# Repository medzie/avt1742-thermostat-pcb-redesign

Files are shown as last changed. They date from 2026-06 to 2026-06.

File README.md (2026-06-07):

# AVT1742 Thermostat - PCB Redesign & Optimization

A hardware cloning and optimization project based on the commercial AVT1742 extended thermostat kit. The core engineering challenge was adapting the original dual-layer design into a strict **single-layer PCB** constraint while systematically improving signal integrity and power routing.

## Key Features & Engineering Challenges

* **Single-Layer Constraint:** Redesigned the entire circuit from scratch to fit a single copper layer (Bottom) to meet strict manufacturing limitations.
* **Solid Ground Pour:** Replaced the original fragmented ground tracks with a continuous copper ground pour. This significantly lowers ground impedance and improves the overall noise immunity of the comparator circuits.
* **Component Placement Optimization:** Relocated decoupling capacitors (C4, C5) significantly closer to the IC power pins (`VCC`/`GND` of LM393 and CD4011) to minimize parasitic inductance and optimize decoupling efficiency.
* **Proven Hardware:** The board was successfully manufactured, soldered, and fully tested. It is 100% operational.

## Technical Overview

* **Core ICs:** LM393 (Low-Power Dual Voltage Comparator), CD4011 (Quad 2-Input NAND Gate)
* **Sensor:** NTC 22kΩ Thermistor
* **Outputs:** 3x Open-Collector outputs with LED status indicators (Too Low, Temp OK, Too High)
* **CAD Software:** Autodesk Eagle

## Repository Structure

* `hardware/` - Eagle CAD schematic (`.sch`) and PCB layout (`.brd`) files.
* `docs/` - Technical documentation, university project report, and original kit datasheets.
* `photos/` - Visual assets, including schematic captures, layout configurations, and hardware testing.

## Gallery & Visualization

### Hardware & PCB Design
Here is the redesigned single-layer PCB layout with the optimized component placement and solid ground pour:

* **Schematic Preview:**
Schematic Preview

* **PCB Layout & Tracks (Bottom Layer):**
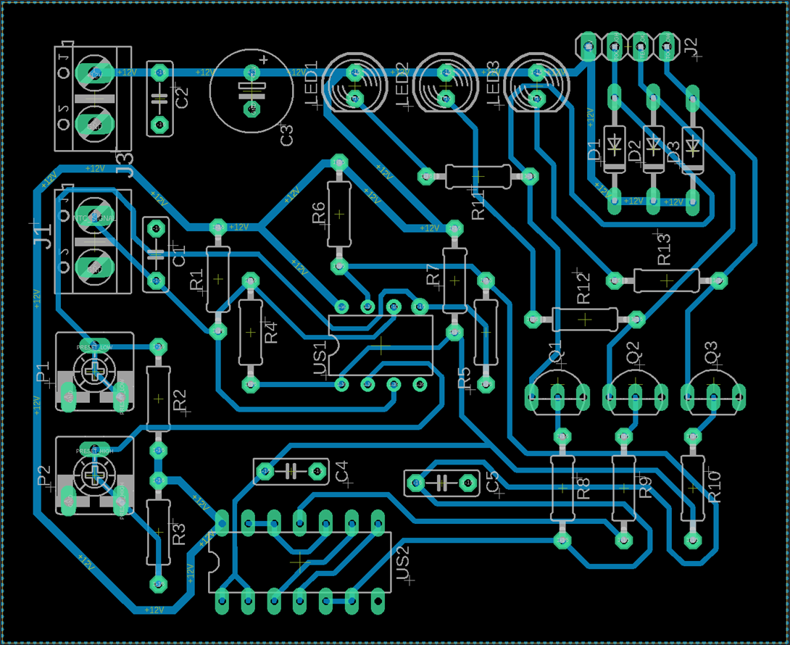
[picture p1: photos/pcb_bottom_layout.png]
PCB Layout


### Assembled & Working Device
Photos of the manufactured, soldered, and fully operational thermostat circuit:

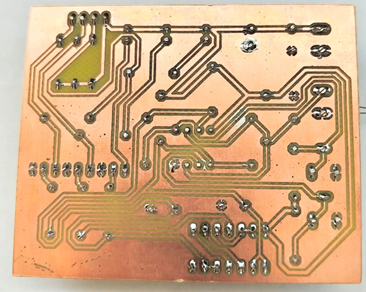
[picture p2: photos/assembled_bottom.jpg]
Assembled Board

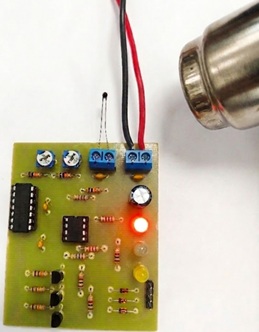
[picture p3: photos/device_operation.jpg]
Device in Action


---
*Project developed as part of engineering coursework.*

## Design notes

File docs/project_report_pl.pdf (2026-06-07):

WYDZIAŁ ELEKTRYCZNY
Studia niestacjonarne

Laboratorium Projektowanie i konstrukcja urządzeń

Data wykonania ćwiczenia: 24.05.2026 | Nazwisko Imię:
| Magdalena Woźniak
| Prowadzący:
| Łukasz Łatfis Semestr:
Data oddania sprawozdania: 06.06.2026 | 4

Temat: Wykonanie, montaż i uruchomienie
własnego układu elektronicznego | Rok: 2

### 1. Cel ćwiczenia

Praktyczne wykonanie płytki drukowanej (PCB) w warunkach pracowni, montaż elementów przewlekanych (THT) oraz test poprawnego działania układu.

### 2. Opis działania układu (AVT1742) Układ pełni funkcję dwustanowego termostatu

okienkowego, którego zadaniem jest monitorowanie, czy temperatura znajduje się w określonym przedziale. Sercem układu jest podwójny komparator analogowy LM393, który porównuje napięcie z czujnika temperatury (termistora NTC) z napięciami odniesienia ustawianymi za pomocą dwóch potencjometrów montażowych (odpowiedzialnych za próg dolny i górny). Sygnały z komparatora trafiają na bramki logiczne układu CD4011, które sterują zapalaniem odpowiedniej diody LED: pomarańczowej (zbyt niska temperatura), zielonej (temperatura w normie) lub czerwonej (przekroczenie progu górnego).

### 2. Wykaz aparatury i materiałów

- Laminat pokryty emulsją światłoczułą
- Przezroczysta folia z nadrukowaną mozaiką ścieżek
- Naświetlarka UV
- Wywoływacz, wytrawiarka z nadsiarczanem sodu
- Wiertarka stołowa (wiertła 0.8 mm, 1.0 mm),
- Stacja lutownicza, cyna (Sn63Pb37),
- Lutownica, zasilacz laboratoryjny 12V, opalarka, multimetr.

### 3. Przebieg prac

1. Trawienie: Płytkę wytrawiono w roztworze Na2S2O8 w temperaturze ok. 45°C przy włączonym napowietrzaniu (czas: ok. 15 minut) a następnie opłukano wodą.
2. Wiercenie: Na wiertarce stołowej wykonano otwory pod elementy:
- 0.8 mm: rezystory, diody, podstawki pod układy scalone, tranzystory
- 1.0 mm: potencjometry, złącza, piny
3. Montaż: Polutowano elementy metodą THT, zaczynając od najniższych (rezystory), kończąc na najwyższych (złącza i kondensator). Układy scalone (LM393 i CD4011) umieszczono w podstawkach, aby ich nie przegrzać.

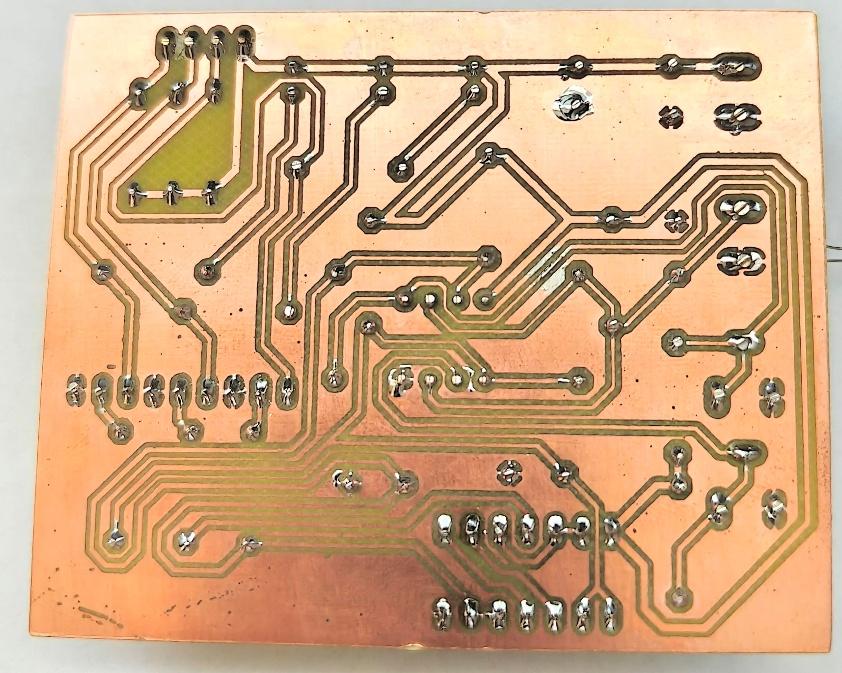
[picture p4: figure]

### 4. Test działania i uruchomienie

Przed podłączeniem zasilania sprawdzono multimetrem brak zwarć na liniach zasilających. Układ podłączono pod zasilacz laboratoryjny 12 V.
- Temperatura ciała człowieka: Układ działa prawidłowo – świeci się zielona dioda (temperatura w zadanym oknie).

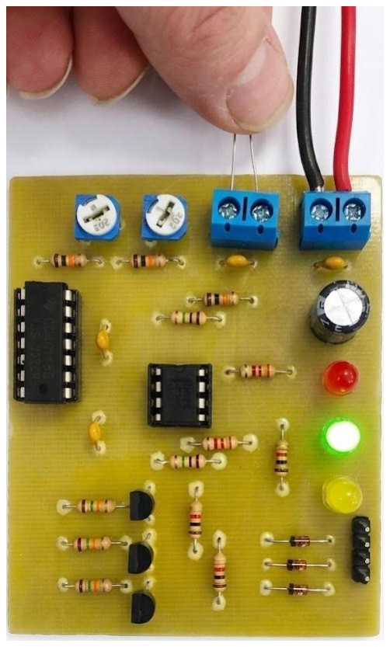
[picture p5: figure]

- Temperatura poniżej ustawionej: świeci się pomarańczowa dioda (temperatura poniżej zadanego okna).

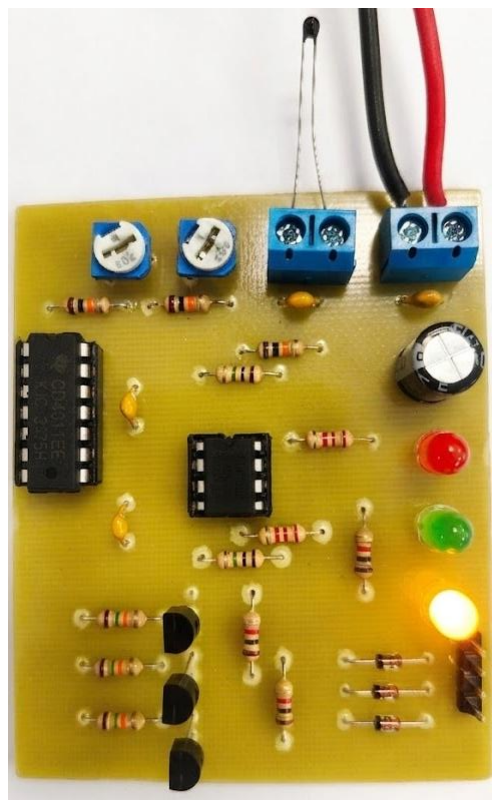
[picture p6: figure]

- Test opalarką: Po skierowaniu strumienia ciepłego powietrza z opalarki na termistor NTC, jego rezystancja spadła. Układ natychmiast zareagował: zgasła dioda zielona, a zapaliła się czerwona (przekroczenie progu górnego). Po ostygnięciu czujnik samoczynnie powrócił do stanu pomarańczowego.

### 5. Wnioski

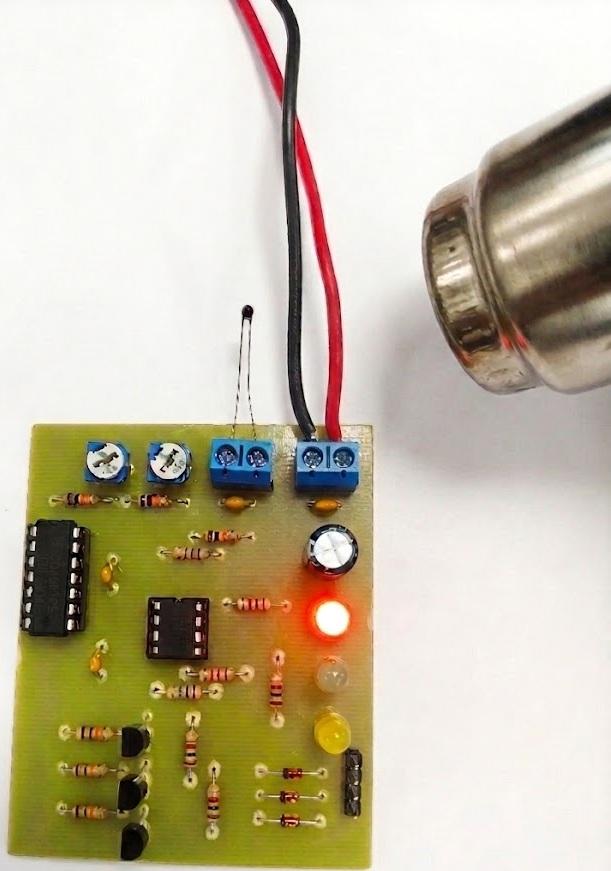
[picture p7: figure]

- Proces wytrawiania i wiercenia przebiegł pomyślnie - ścieżki są ciągłe i niepodtrawione.
- Lutowanie THT wykonano prawidłowo, brak zimnych lutów.
- Układ AVT 1742 przeszedł testy dynamiczne (reakcja na ciepło z opalarki) i wykazuje pełną sprawność funkcjonalną.

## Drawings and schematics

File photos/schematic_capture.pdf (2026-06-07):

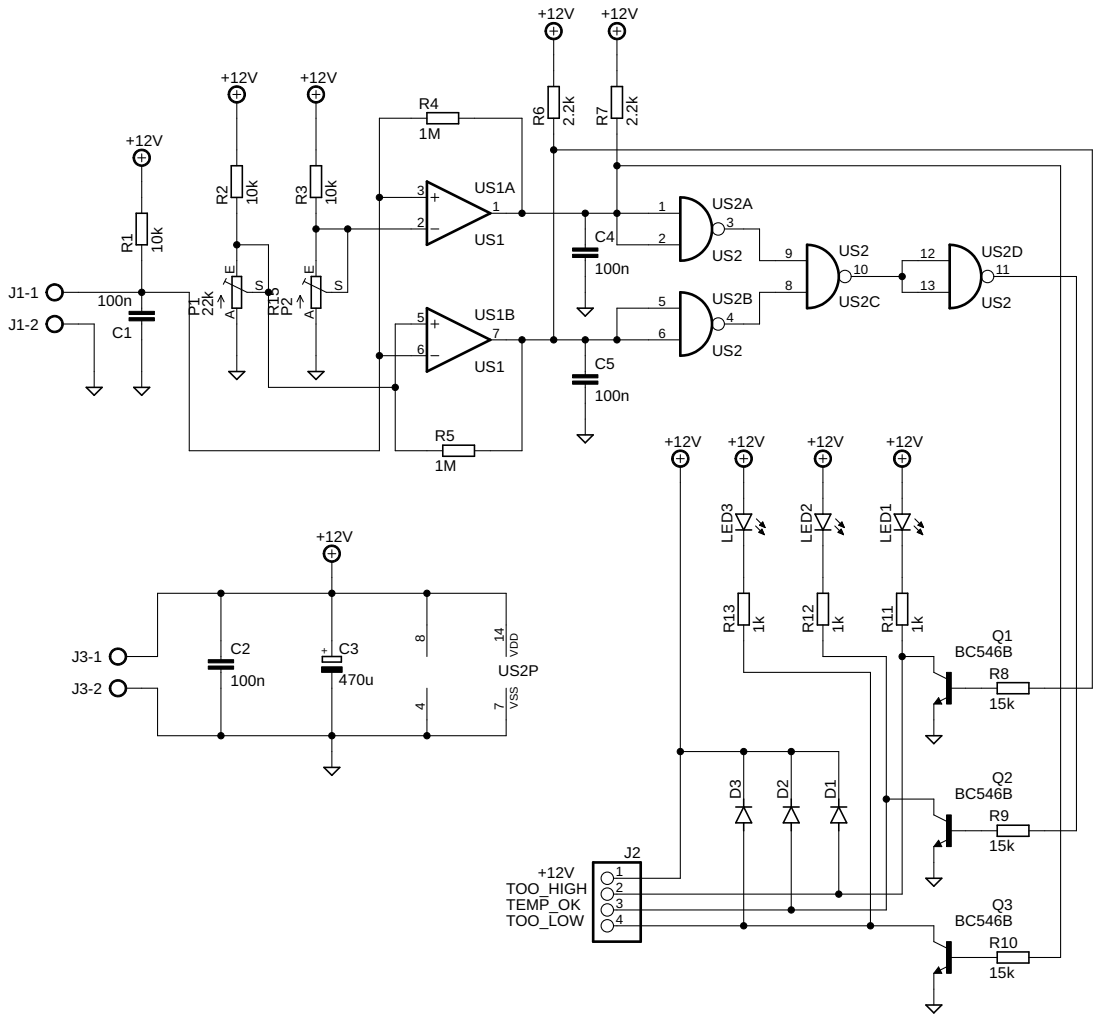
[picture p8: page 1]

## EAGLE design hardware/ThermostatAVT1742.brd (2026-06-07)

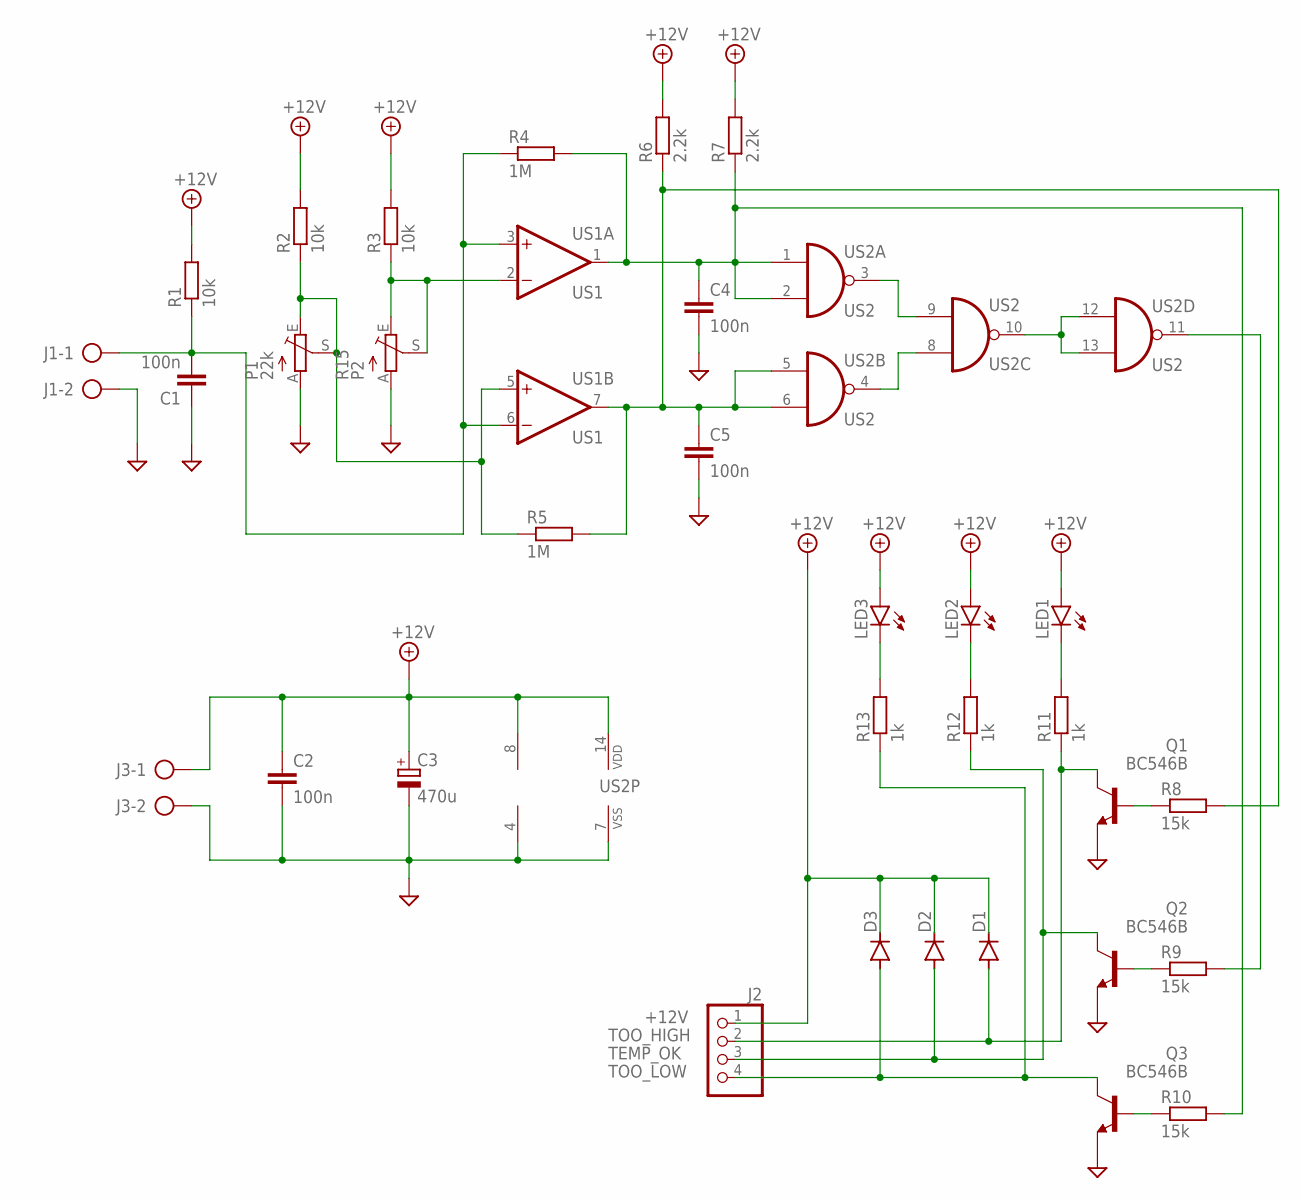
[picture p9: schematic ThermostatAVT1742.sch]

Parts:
C1, C2, C4, C5: 100n; C050-025X075
C3: 470u; E3,5-8
D1: red; DO35-10
D2: green; DO35-10
D3: yellow; DO35-10
J1: J1; AK500/2
J2: J2; 1X04
J3: J3; AK500/2
LED1: red; LED5MM
LED2: green; LED5MM
LED3: yellow; LED5MM
P1: 22k; CA6V
Q1, Q2, Q3: BC546B; TO92-EBC
R1, R2, R3: 10k; 0207/10
R4, R5: 1M; 0207/10
R6, R7: 2.2k; 0207/10
R8, R9, R10: 15k; 0207/10
R11, R12, R13: 1k; 0207/10
R15: P2; CA6V
US1: US1; DIL08
US2: US2; DIL14

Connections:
+12V: C2.1, C3.+, D1.C, D2.C, D3.C, J2.1, J3.1, LED1.A, LED2.A, LED3.A, R1.2, R2.2, R3.2, R6.2, R7.2, US1.8 (V+), US2.14 (VDD)
BASE_HIGH: Q1.B, R8.1
BASE_LOW: Q3.B, R10.1
BASE_OK: Q2.B, R9.1
GND: C1.1, C2.2, C3.-, C4.2, C5.2, J1.2, J3.2, P1.A, Q1.E, Q2.E, Q3.E, R15.A, US1.4 (V-), US2.7 (VSS)
L_GREEN: LED2.K (C), R12.2
L_RED: LED1.K (C), R11.2
L_YELLOW: LED3.K (C), R13.2
NTC_SIGNAL: C1.2, J1.1, R1.1, R4.1, US1.3 (+IN), US1.6 (-IN)
OUT_HI_LOGIC: C4.1, R4.2, R7.1, R10.2, US1.1 (OUT), US2.1 (I0), US2.2 (I1)
OUT_LO_LOGIC: C5.1, R5.2, R6.1, R8.2, US1.7 (OUT), US2.5 (I0), US2.6 (I1)
PRESET_HIGH: R3.1, R15.E, R15.S, US1.2 (-IN)
PRESET_LOW: P1.E, P1.S, R2.1, R5.1, US1.5 (+IN)
SYGNAL_A: US2.3 (O), US2.9 (I1)
SYGNAL_B: US2.4 (O), US2.8 (I0)
TEMP_OK: D2.A, J2.3, Q2.C, R12.1
TEMP_OK_FINAL: R9.2, US2.11 (O)
TEMP_OK_NEG: US2.10 (O), US2.12 (I0), US2.13 (I1)
TOO_HIGH: D1.A, J2.2, Q1.C, R11.1
TOO_LOW: D3.A, J2.4, Q3.C, R13.1

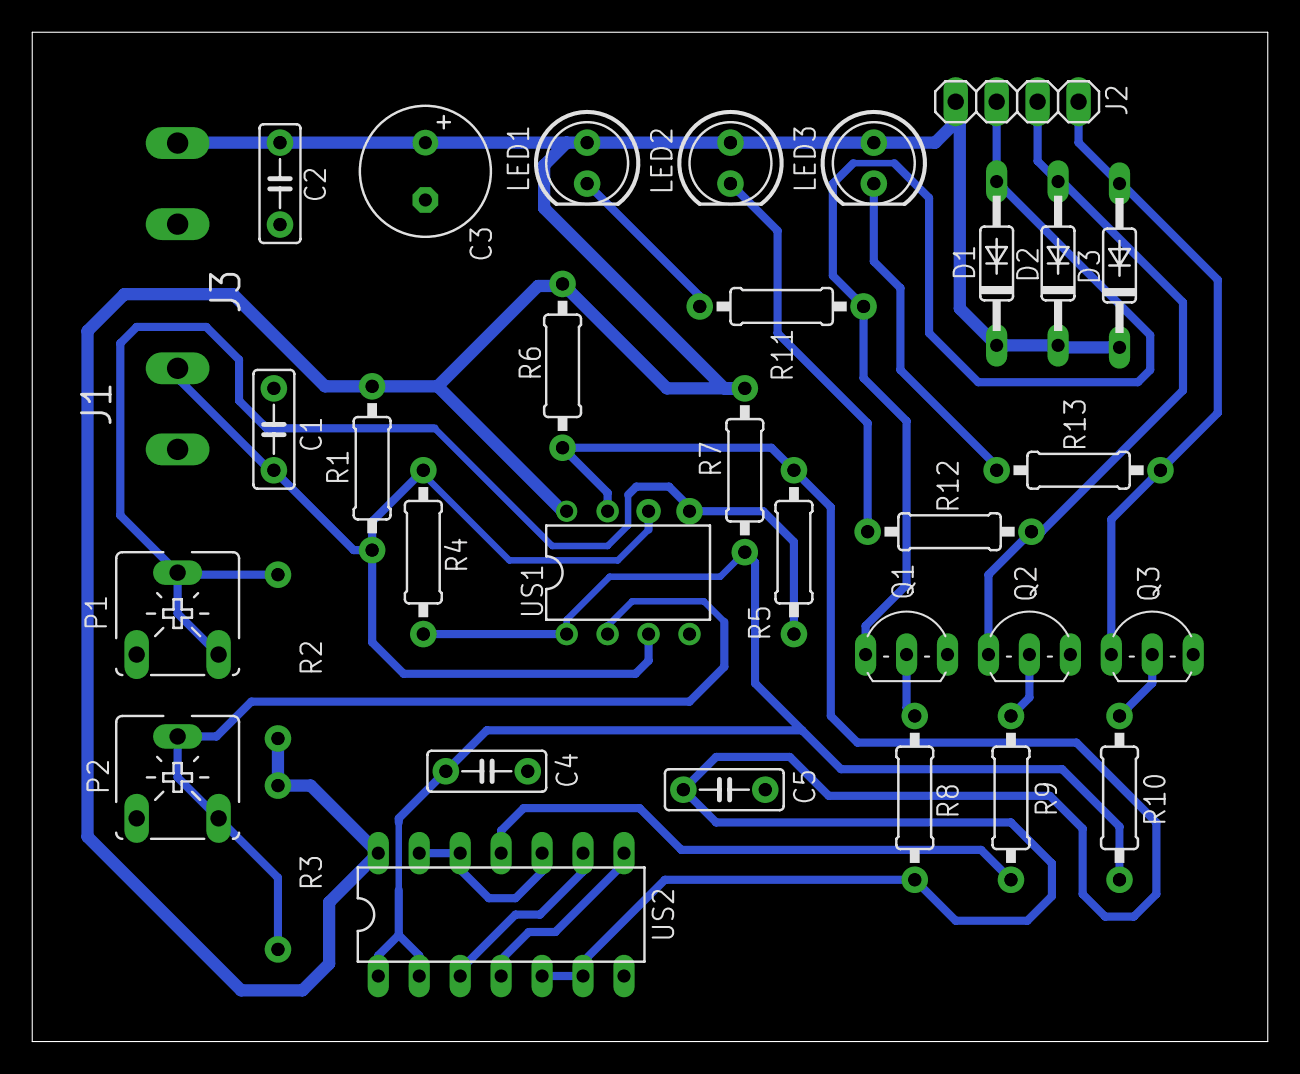
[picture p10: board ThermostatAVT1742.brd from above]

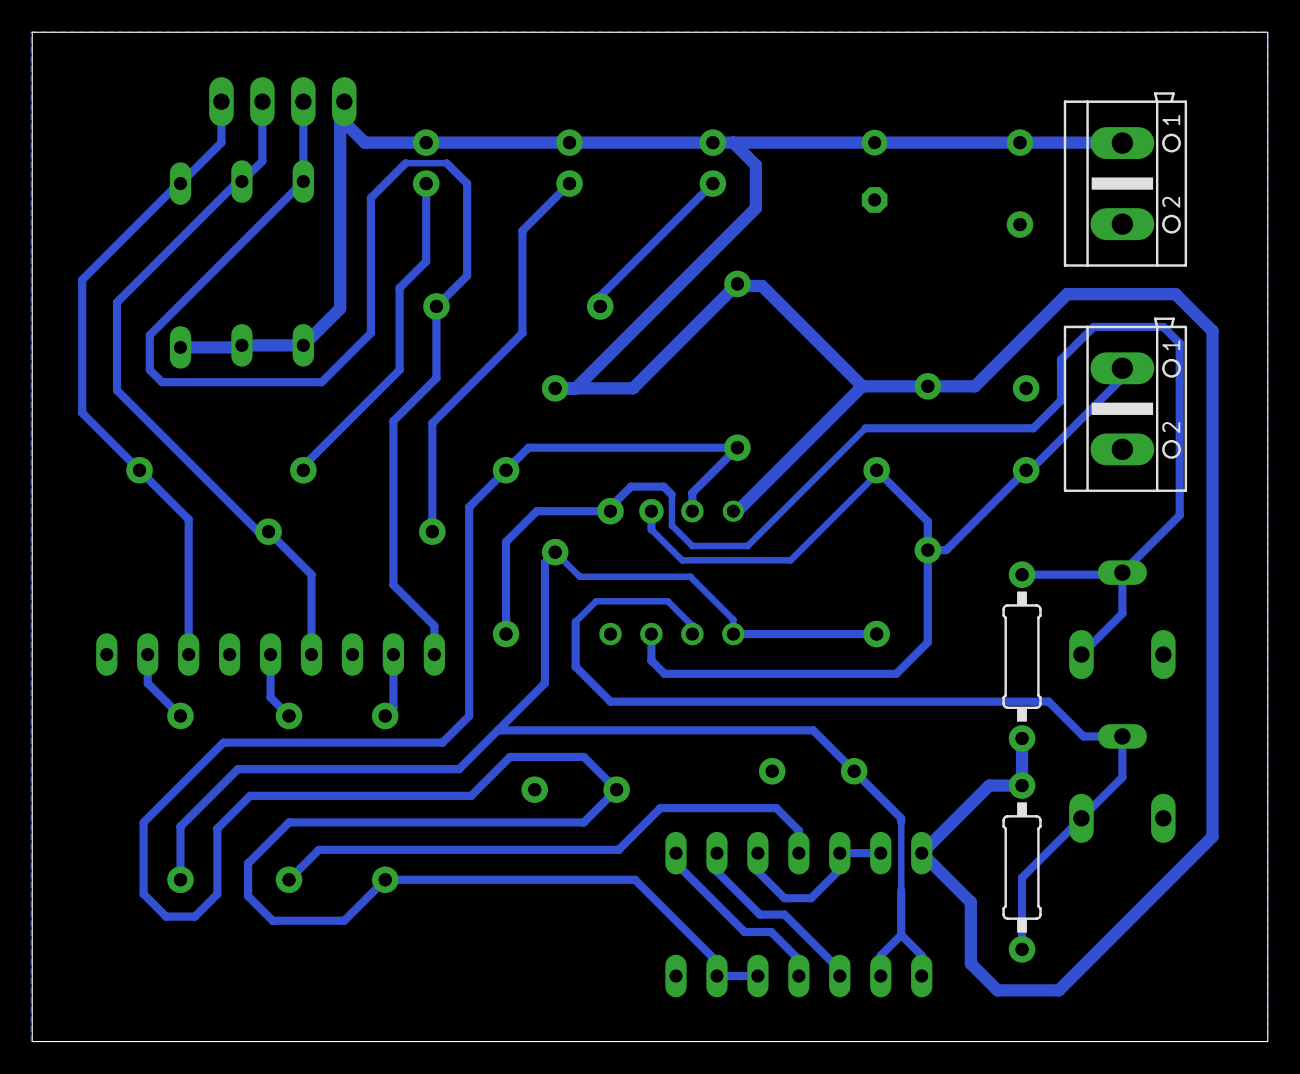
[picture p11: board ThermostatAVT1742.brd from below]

Board: 2 copper layers, 76.6 x 62.6 mm, 34 parts (4 on the bottom side), 20 nets.

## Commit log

2026-06-07 docs: Initial commit with single-layer hardware redesign and photos
    [ThermostatAVT1742.brd, ThermostatAVT1742.sch]
2026-06-07 Change schematic preview image to PDF format
    Updated schematic preview image format from PNG to PDF.
